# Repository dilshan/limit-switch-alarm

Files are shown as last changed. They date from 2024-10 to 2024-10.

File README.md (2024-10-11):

## Alarm unit for limit switches or flow switches

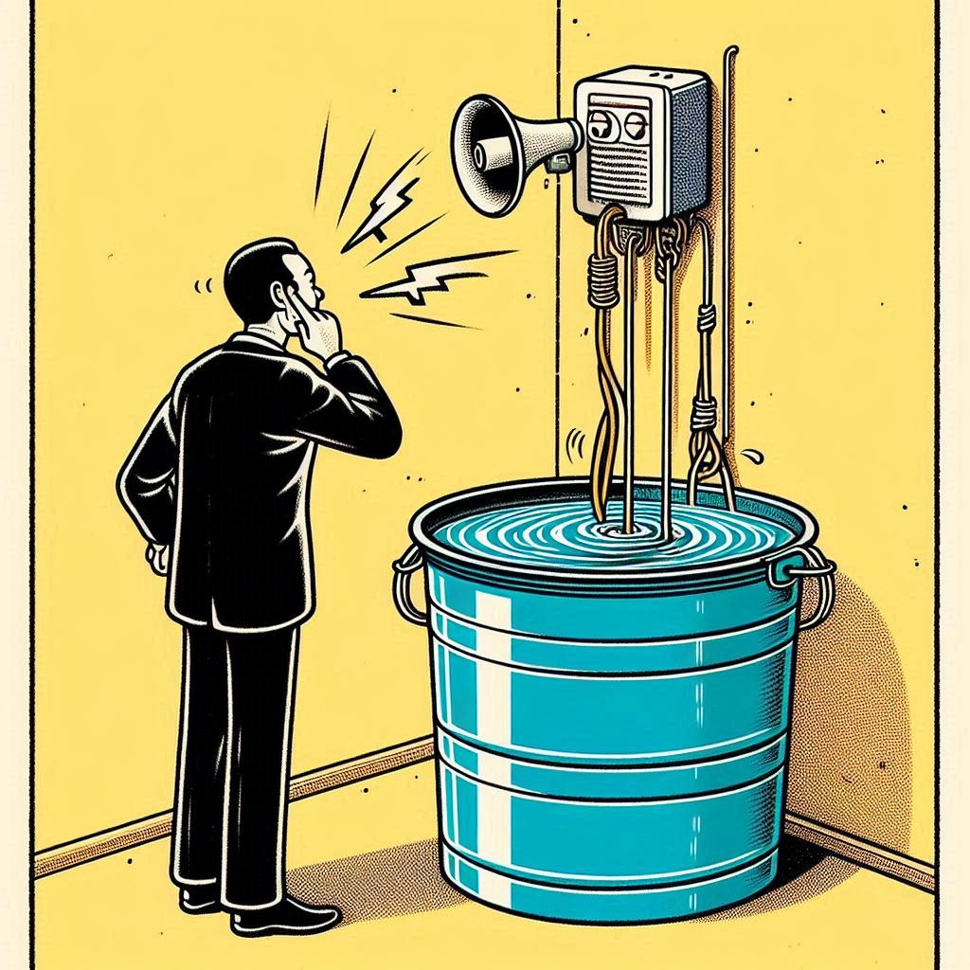
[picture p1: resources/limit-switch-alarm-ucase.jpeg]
Alarm controller in action


This project introduces a cost-effective and do-it-yourself (DIY) solution for monitoring floater switches and activating alarms in various applications. The designed circuit, which is based on the PIC12F508 microcontroller, effectively detects changes in floater switch status and triggers the alarm. The system is designed to operate with a 12V DC power supply and utilizes a 230V AC buzzer unit for audible alerts.

The circuit includes a mute function that temporarily silences the alarm for a specified duration. Additionally, a built-in timeout mechanism ensures continuous alarm activation if the floater switch remains closed for an extended period, indicating a potential emergency. The project's modular design and clear documentation facilitate easy assembly and customization, making it suitable for a wide range of applications, including home automation, industrial monitoring, and environmental sensing.

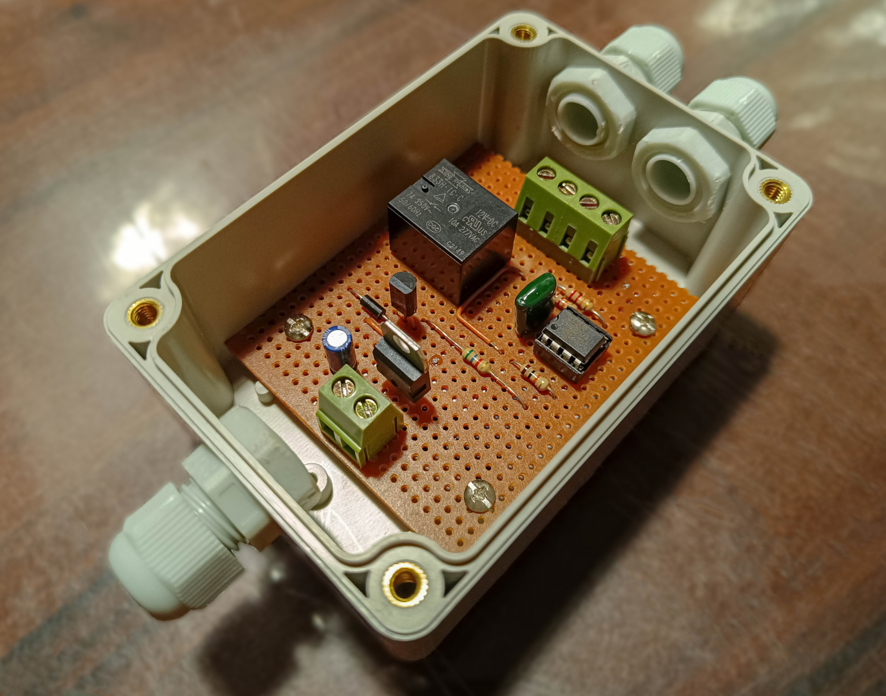
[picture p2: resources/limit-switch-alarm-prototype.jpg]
Prototype version of alarm controller


### Bill of materials

| Reference  | Value | Qty | Datasheet |
|---|---|-----|---|
| C101 | [100µF / 16V](https://s.click.aliexpress.com/e/_EJ7MXe9) | 1 | |
| C102 | [0.1µF / 50V](https://s.click.aliexpress.com/e/_oCeppvT) | 1 | |
| D101 | [1N4007](https://s.click.aliexpress.com/e/_ExTh0Mz) | 1 | http://www.vishay.com/docs/88503/1n4001.pdf |
| K101 | [JQC-3F-12VDC-1ZS](https://s.click.aliexpress.com/e/_EyyWHrr) | 1 | https://www.futurlec.com/Datasheet/Relays/JQC-3FF.pdf |
| Q101 | [2SD400](https://s.click.aliexpress.com/e/_mNK5TeM) | 1 | https://datasheet.octopart.com/2SD400-Sanyo-datasheet-101823.pdf |
| R101 | [10KΩ](https://s.click.aliexpress.com/e/_EJJGJg1) | 1 | |
| R102 | [5.6KΩ](https://s.click.aliexpress.com/e/_EJJGJg1) | 1 | |
| R103, R104 | [22KΩ](https://s.click.aliexpress.com/e/_EJJGJg1) | 2 | |
| U101 | [PIC12F508-I/P](https://s.click.aliexpress.com/e/_EvdDNTr) | 1 | https://ww1.microchip.com/downloads/en/DeviceDoc/41236E.pdf |
| U102 | [L7805](https://s.click.aliexpress.com/e/_opm5dbr) | 1 | https://www.st.com/resource/en/datasheet/l78.pdf |

### PIC12F508 firmware

The firmware for this project is developed using the [MPLAB X IDE](https://www.microchip.com/en-us/tools-resources/develop/mplab-x-ide) and the [XC8 C compiler](https://www.microchip.com/en-us/tools-resources/develop/mplab-xc-compilers). The latest firmware is available in the [/firmware](https://github.com/dilshan/limit-switch-alarm/tree/main/firmware) directory in this repository. 

### External Components

This project requires several external components:

- [12V 1A Power Supply Unit (PSU)](https://s.click.aliexpress.com/e/_mqQEkSY): Provides the necessary power for the microcontroller, relay, and other electronic components.
- [Pump Float Switch](https://s.click.aliexpress.com/e/_EuamfjX): A float switch is used to detect changes in liquid levels. Select a float switch that is compatible with the intended application and capable of reliably triggering the alarm system.
- [AC High dB Mechanical Buzzer](https://s.click.aliexpress.com/e/_oBIDYBj) or [Industrial Alarm](https://s.click.aliexpress.com/e/_oDt7jiN): A loud and attention-grabbing alarm is essential for alerting users to potential emergencies. Consider using an AC-powered mechanical buzzer or industrial alarm that is suitable for the desired noise level.
- [Push Switch](https://s.click.aliexpress.com/e/_EvkMX2H): A momentary push switch is used to manually mute the alarm.

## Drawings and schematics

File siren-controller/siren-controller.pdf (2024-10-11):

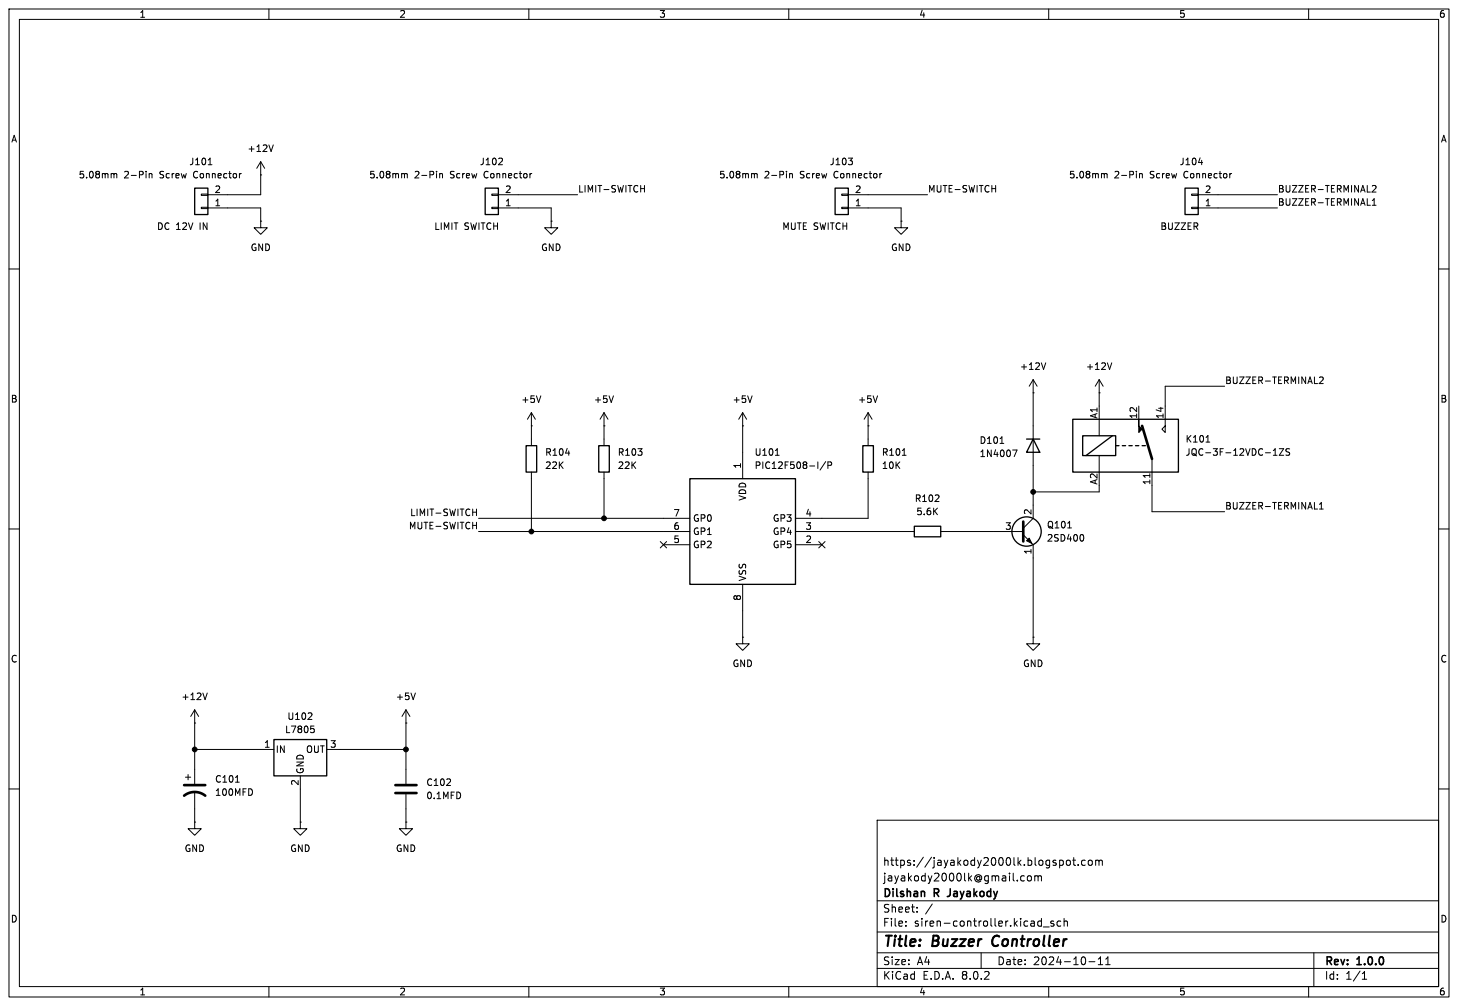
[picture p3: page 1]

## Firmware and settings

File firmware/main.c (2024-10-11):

/*
 * File:   main.c
 * Project: A simple alarm controller for limit switch or flow switches.
 * Author: Dilshan R Jayakody [jayakody2000lk@gmail.com]
 * 
 * https://github.com/dilshan/limit-switch-alarm
 *
 * Created on October 6, 2024, 12:46 PM
 * 
 * MIT License
 * 
 * Copyright (c) 2024 Dilshan R Jayakody
 * 
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
 * THE SOFTWARE IS PROVIDED "AS IS", WITHOUT WARRANTY OF ANY KIND, EXPRESS OR
 * IMPLIED, INCLUDING BUT NOT LIMITED TO THE WARRANTIES OF MERCHANTABILITY,
 * FITNESS FOR A PARTICULAR PURPOSE AND NONINFRINGEMENT. IN NO EVENT SHALL THE
 * AUTHORS OR COPYRIGHT HOLDERS BE LIABLE FOR ANY CLAIM, DAMAGES OR OTHER
 * LIABILITY, WHETHER IN AN ACTION OF CONTRACT, TORT OR OTHERWISE, ARISING FROM,
 * OUT OF OR IN CONNECTION WITH THE SOFTWARE OR THE USE OR OTHER DEALINGS IN THE
 * SOFTWARE.
 */

#include "fuseconfig.h"
#include <xc.h>

#define ALARM_RUNNING   0x01
#define ALARM_MUTE      0x02
#define BUZZER_PLUSE    0x04
#define BUZZER_CONTINUE 0x08

#define BASE_TIMER_LIMIT  900   // Closer to 10 second (adjusted by considering the code execution delays).
#define MUTE_TIMEOUT_LIMIT  30  // Closer to 5 minutes. (MUTE_TIMEOUT_LIMIT * 10 * BASE_TIMER_LIMIT)/(60 * 1000)

#define RING_CONTINUE_LIMIT 20

// Buzzer on and off delay limits.
#define RING_OFF_LIMIT  750
#define RING_ON_LIMIT   250

void main(void)
{
  // Enable weak pull-ups on GP0 and GP1.
  OPTION = 0x40;
  
  // Configure GPIO
  // GP0 - [IN]  - Limit switch input.
  // GP1 - [IN]  - Mute switch input.
  // GP4 - [OUT] - Buzzer control relay.
  TRISGPIO = 0x03;
  GPIO = 0x03;
  
  unsigned char controllerState = 0x00;
  unsigned char timeout = 0, buzzerCount = 0;
  unsigned short baseTimer = 0, pulseTimer = 0;
  
  while(1)
  {
      // Check limit switch is triggered.
      if((GPIO & 0x01) == 0x00)
      {
        if((controllerState & ALARM_RUNNING) == 0x00)
        {
          // New trigger has been detected!
          controllerState = controllerState | ALARM_RUNNING;
          
          // Turn on relay output.
          GPIO = GPIO | 0x10;
        }
      }
      else
      {
        // Limit switch is in open position.
        if(controllerState & ALARM_RUNNING)
        {
          // Just now the limit switch has been released! (and reset everything!)
          controllerState = 0;
          buzzerCount = 0;
          timeout = 0;
          pulseTimer = 0;
          baseTimer = 0;
          
          // Turn off relay output.
          GPIO = GPIO & 0xEF;
        }
      }
      
      // Check mute switch is pressed by the user.
      if((GPIO & 0x02) == 0x00)
      {
        // Check limit switch is still in limit.
        if(controllerState & ALARM_RUNNING)
        {
          controllerState = controllerState | ALARM_MUTE;  
          timeout = 0;
          
          // Turn off relay output.
          GPIO = GPIO & 0xEF;
        }
      }
      
      // Timeout counter.
      if(controllerState & ALARM_MUTE)
      {
        if((++baseTimer) >= BASE_TIMER_LIMIT)
        {
          // base time delay has been reached (10 seconds in default configuration)!
          baseTimer = 0; 
          
          if((++timeout) >= MUTE_TIMEOUT_LIMIT)
          {
            // mute timeout delay has been reached!
            timeout = 0;
            
            controllerState = controllerState & (~ALARM_MUTE);
          }
        }
      }
      
      // Handle buzzer delays in continues operation...
      if((controllerState & ALARM_RUNNING) && ((controllerState & ALARM_MUTE) == 0x00) 
                                           && ((controllerState & BUZZER_CONTINUE) == 0x00))
      {
        // Alarm is running and to avoid buzzer heat-ups, lets pulse the output.
        if(((controllerState & BUZZER_PLUSE) == 0x00) && ((++pulseTimer) >= RING_OFF_LIMIT))
        {
          // Turn off buzzer (15sec in default configuration)!
          GPIO = GPIO & 0xEF;   
          pulseTimer = 0;
          controllerState = controllerState | BUZZER_PLUSE;
        }
        
        if((controllerState & BUZZER_PLUSE) && ((++pulseTimer) >= RING_ON_LIMIT))
        {
          
          // Turn on buzzer (5sec in default configuration)!
          GPIO = GPIO | 0x10;
          pulseTimer = 0;
          controllerState = controllerState & (~BUZZER_PLUSE);
          buzzerCount++;
        } 

        // After defined beep cycles, buzzer starts to ring continuously...
        if(buzzerCount > RING_CONTINUE_LIMIT)
        {
          GPIO = GPIO | 0x10;
          controllerState = controllerState | BUZZER_CONTINUE;
        }
      }
      
      __delay_ms(10);
  }
  
  return;
}
